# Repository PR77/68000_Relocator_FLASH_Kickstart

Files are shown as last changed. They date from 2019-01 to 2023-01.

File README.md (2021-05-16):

# 68000 Relocator with FLASH based Kickstart
Forked from https://github.com/AwesomeInferno/68000Relocator and modified to support FLASH Kickstart allowing programming in system.

# Warning
This design has not been compliance tested and will not be. It may cause damage to your A500. I take no responsibility for this. I accept no responsibility for any damage to any equipment that results from the use of this design and its components. IT IS ENTIRELY AT YOUR OWN RISK!

# Overview
To allow for Flash Kickstart images to be mapped in the same address space as existing ROM Kickstart without the need to remove the existing ROM. This design is targeting an accelerated A500(+) system which also require a CPU relocation.

### Appearance
Nice 3D model:
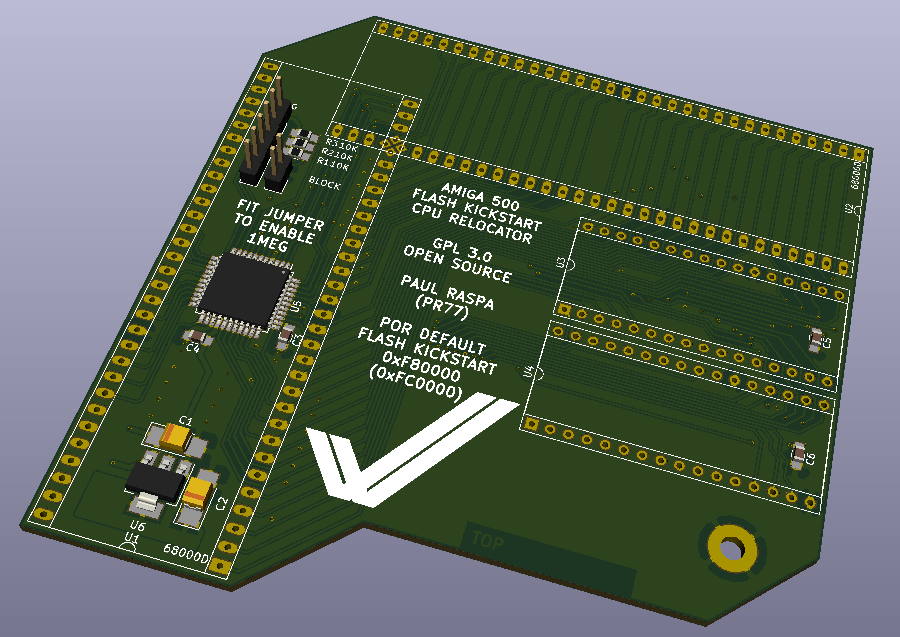
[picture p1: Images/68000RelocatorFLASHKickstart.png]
3D Model


... this is the final design.

### Prototype
Drawing in from the experience and usefulness of my prototyping jig created for my Rev-1 Accelerator (https://github.com/PR77/A500_ACCEL_RAM_IDE-Rev-1), I decided to do the same for this hardware expansion.

So the prototype looks like this:

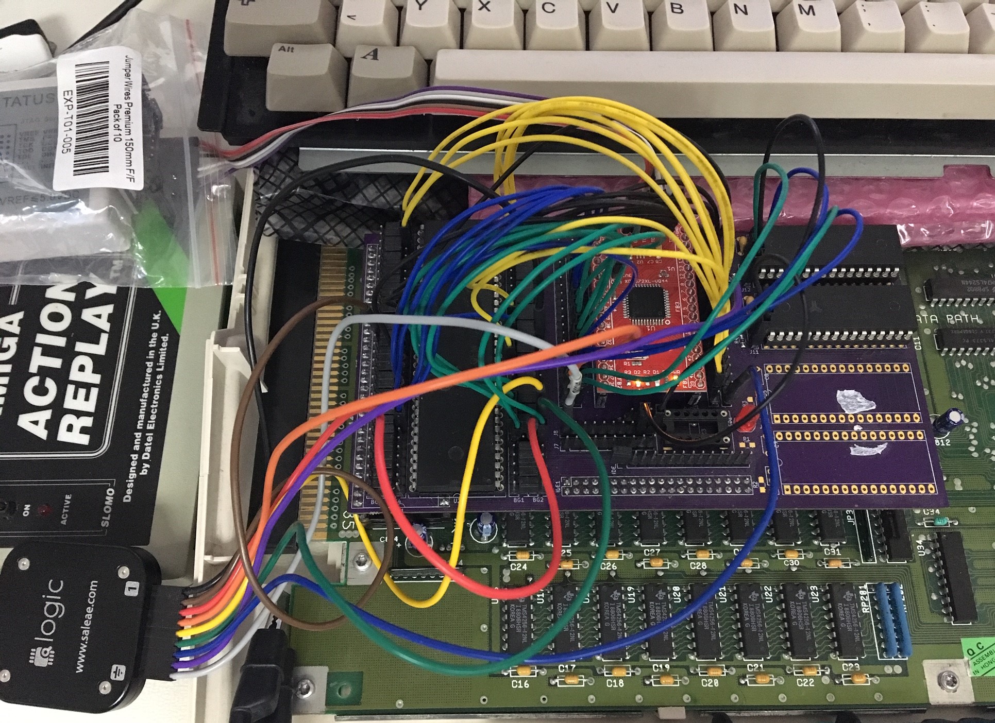
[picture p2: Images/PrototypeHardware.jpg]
Jumpered PCB


To keep the prototype simple, instead of using Flash devices (AMD AM29F040B are my target has I have these and experience with the devices) I used simple SRAMs (also from my Accelerator). There was also the learning curve with using VBCC (http://eab.abime.net/showthread.php?t=83113) to develop the software to control the hardware, but with that sorted out I managed to finally get the prototype to work.

### Final Hardware
Here is the final hardware loaded and installed with my Rev-2 Accelerator (https://github.com/PR77/A500_ACCEL_RAM_IDE-Rev-2). I was not able to easily source new AMD AM29F040B Flash devices so I changed over to SST39SF0x0A devices. They are JEDEC compliant so no issue with the pinout. Just watch out for the device identification in the SW.

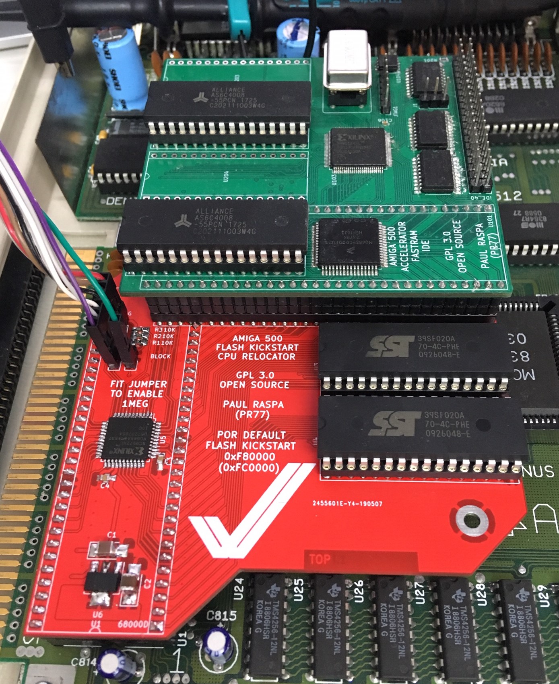
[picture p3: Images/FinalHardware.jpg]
Final PCB


### BOM
For those wanting to build their own hardware, here is the BOM;

| Reference(s) | Value | Footprint |
|---|---|---|
| C1 | 10uF | Capacitors_Tantalum_SMD:CP_Tantalum_Case-B_EIA-3528-21_Hand |
| C2 | 10uF | Capacitors_Tantalum_SMD:CP_Tantalum_Case-B_EIA-3528-21_Hand |
| C3 | 100nF | Capacitors_SMD:C_0805_HandSoldering |
| C4 | 100nF | Capacitors_SMD:C_0805_HandSoldering |
| C5 | 100nF | Capacitors_SMD:C_0805_HandSoldering |
| C6 | 100nF | Capacitors_SMD:C_0805_HandSoldering |
| J3 | BLOCK | Pin_Headers:Pin_Header_Straight_1x02_Pitch2.54mm |
| J4 | JTAG | Pin_Headers:Pin_Header_Straight_1x06_Pitch2.54mm |
| R1 | 10K | Resistors_SMD:R_0805_HandSoldering |
| R2 | 10K | Resistors_SMD:R_0805_HandSoldering |
| R3 | 10K | Resistors_SMD:R_0805_HandSoldering |
| U1 | 68000D | Pin_Headers:Pin_Header_Straight_2x32_Pitch2.54mm |
| U2 | 68000D | Housings_DIP:DIP-64_W22.86mm_Socket_LongPads |
| U3 | SST39SF040 | Housings_DIP:DIP-32_W15.24mm_Socket |
| U4 | SST39SF040 | Housings_DIP:DIP-32_W15.24mm_Socket |
| U5 | XC9572VQ44 | Housings_QFP:TQFP-44_10x10mm_Pitch0.8mm |
| U6 | LM1117-3.3 | TO_SOT_Packages_SMD:SOT-223-3_TabPin2 |

### In Operation
My test Amiga 500 has a ROM Kickstart version 1.2, so the boot screen looks like this:

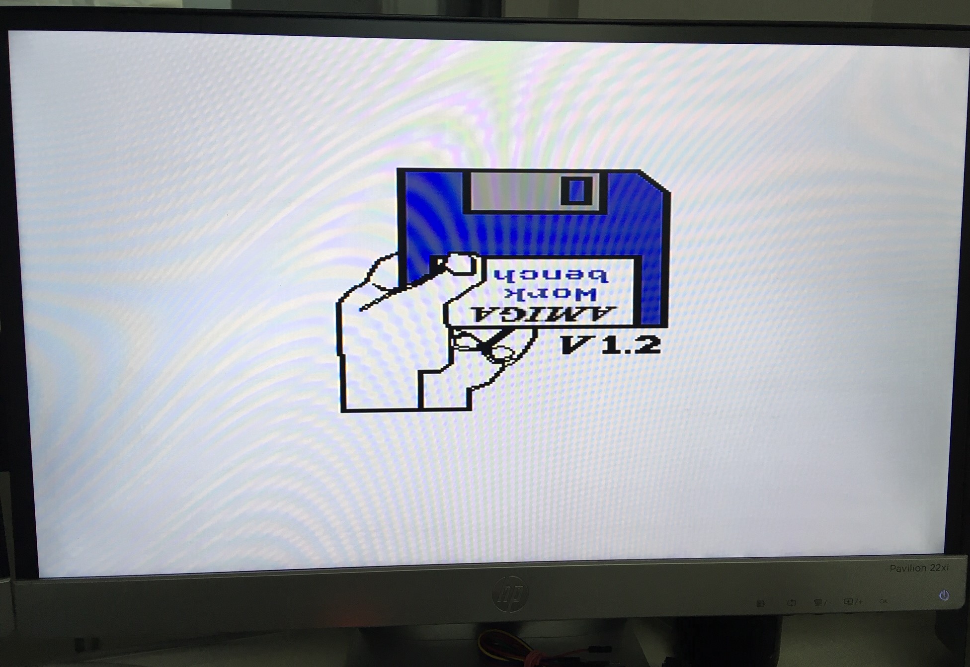
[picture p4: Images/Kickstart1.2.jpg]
ROM Kickstart 1.2


Then when loading into RAM Kickstart version 3.1 the software will make a simple dump of the RAM to the console to ensure it has been written correctly (data blurred to avoid any potential (C) issues). Essentially some basic debugging which looks like this:

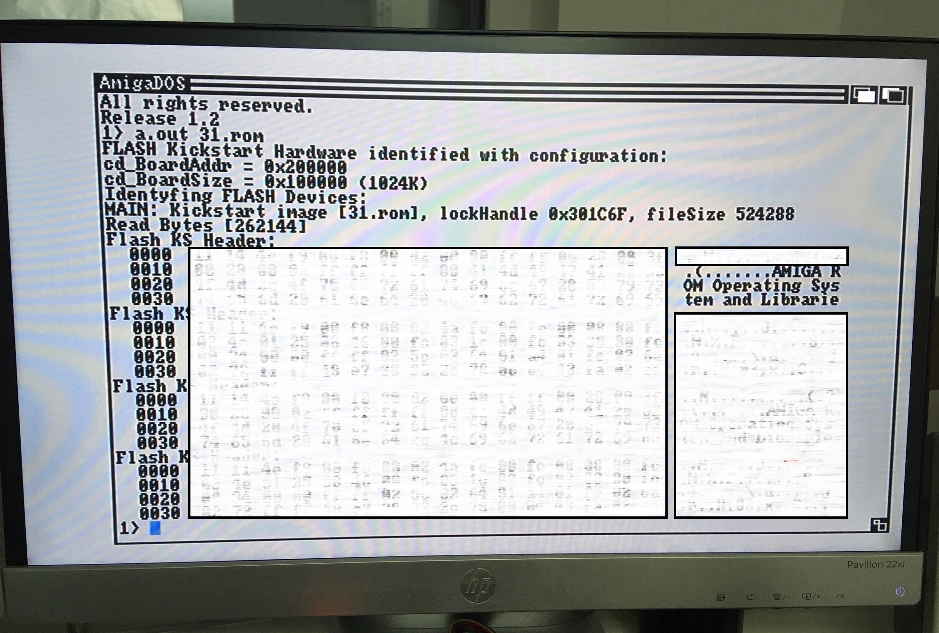
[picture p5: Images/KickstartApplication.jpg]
Application Output


... so now, using the magic sequence, I have Kickstart version 3.1 as shown here:

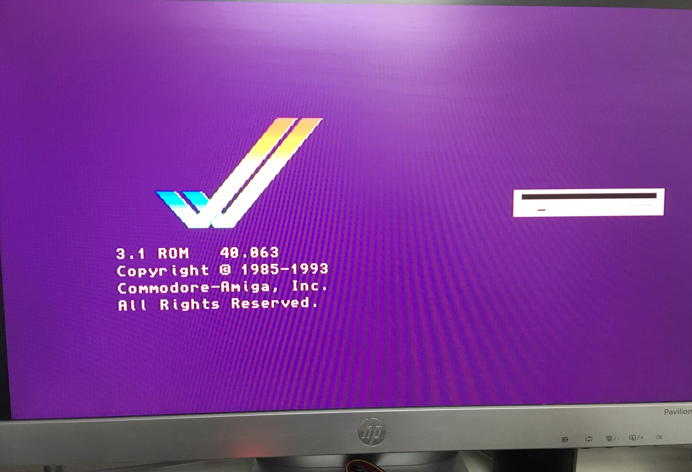
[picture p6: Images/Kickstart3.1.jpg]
ROM Kickstart 3.1


### How It Works
In principle the operation is fairly simple. A CPLD is used to switch between the ROM Kickstart on the Motherboard or the Flash Kickstart on the CPU Relocator. Switching is performed by an active /RESET (CTRL-A-A) without interruption for longer than 1 second. Shorter /RESET durations will simply just reset the Amiga. After a POR (Power On Reset) by default the Flash Kickstart on the CPU Relocator will be used.

#### ROM based Kickstart
When ROM Kickstart is being used, the hardware simply passed /AS to the Amiga Motherboard to allow GARY perform the address decode and chip select of the internal ROM. During this process, the Flash Kickstart is simply not used - except when programming. A Zorro II space of 512K is  requested and allocated by the Amiga which maps to the Flash devices.

When programming the Flash devices, access is via this Zorro II space. Programming of the Flash devices can only be performed when ROM Kickstart is being used.

#### FLASH based Kickstart
When Flash Kickstart is being used, the hardware simply blocks /AS to the Amiga Motherboard and the CPLD will perform the operation of Flash device control. As /AS is not asserted on the Amiga Motherboard, and therefore no GARY decode, the Relocator CPLD will then also assert the /DTACK after placing data on the bus - this is needed to complete the CPU cycle.

Flash Kickstarts will always be visible from base address 0xF80000. This means, if 256K images would be used, then it will need to be duplicated to populate the entire 512K region size. This is to ensure the correct SP and IP initisation (see Overlay Interception). 256K images generally start from address 0xFC0000 (as opposed to 0xF80000).

#### Overlay Interception
When Flash Kickstart mode is being used, the CPLD will also intercept the overlay of the Kickstart in the 0x000000 memory space until the first access to the custom chip register is performed. This ensures the correct SP and IP initialisation is performed directly after POR (Power On Reset) as the Flash Kickstart is used by default.

### Known Issues And Pending Items
The following items are pending:

1. Will update the software to not load the entire Kickstart content into RAM before programming; rather will load 64K chunks at a time.
2. Support for ROMs based at address 0xF00000.

### External Contributions
Thanks to the Open Source efforts, here is a list of improvements people have made:

1. Side Slot expander version and GUI - https://github.com/KaiEmilW/A500-Side-Expansion-Slot-CPU-Relocator

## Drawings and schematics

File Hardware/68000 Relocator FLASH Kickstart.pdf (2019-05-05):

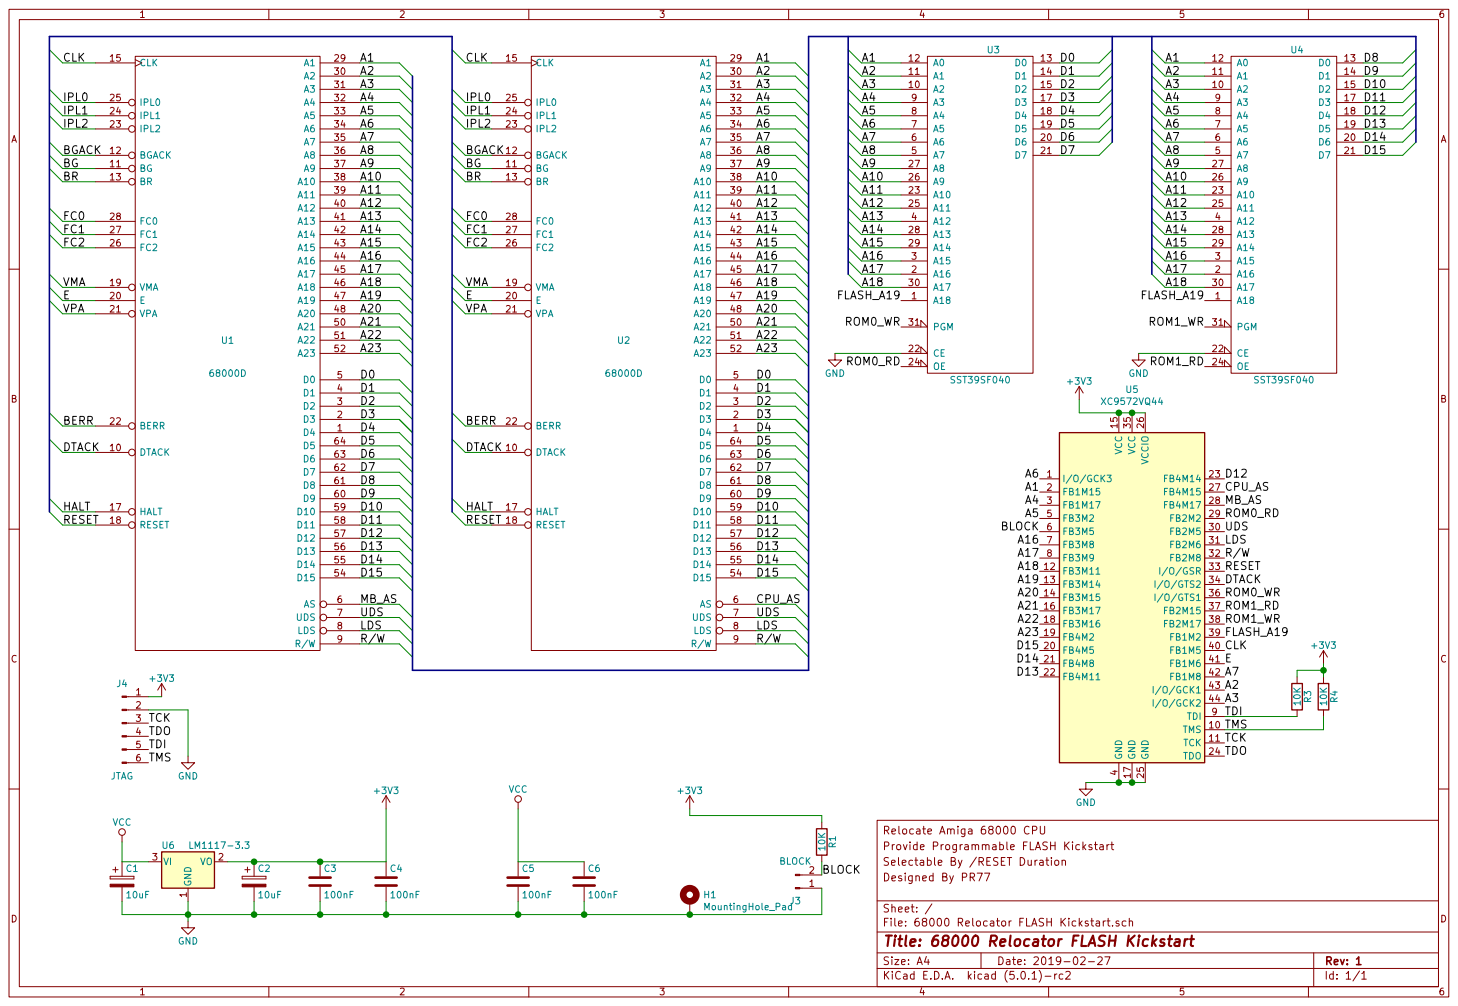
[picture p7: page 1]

Relocate Amiga 68000 CPU
Provide Programmable FLASH Kickstart
Selectable By /RESET Duration
Id: 1/1 Title: 68000 Relocator FLASH Kickstart File: 68000 Relocator FLASH Kickstart.sch Sheet: / Designed By PR77

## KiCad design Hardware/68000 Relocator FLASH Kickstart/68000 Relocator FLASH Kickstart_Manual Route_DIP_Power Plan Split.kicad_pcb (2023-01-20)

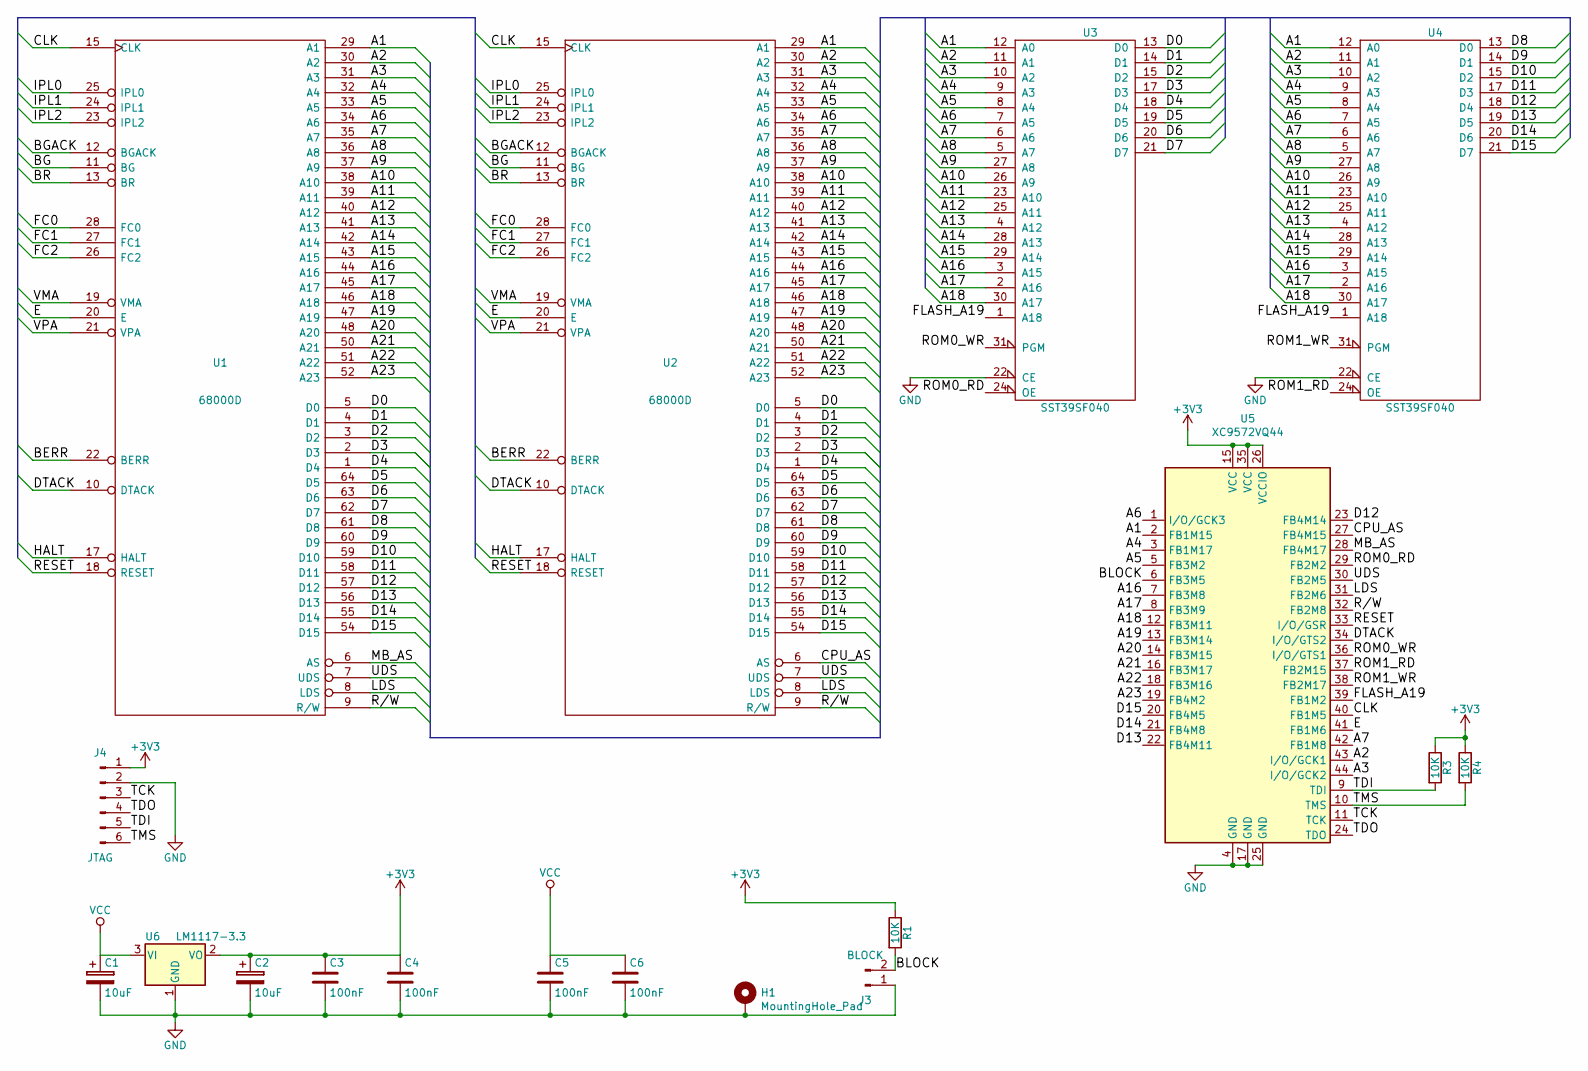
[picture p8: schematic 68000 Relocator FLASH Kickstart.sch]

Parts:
C1, C2: 10uF; CP_Tantalum_Case-B_EIA-3528-21_Hand
C3, C4, C5, C6: 100nF; C_0805_HandSoldering
H1: MountingHole_Pad; MountingHole_3.2mm_M3_Pad
J3: BLOCK; Pin_Header_Straight_1x02_Pitch2.54mm
J4: JTAG; Pin_Header_Straight_1x06_Pitch2.54mm
R1, R3, R4: 10K; R_0805_HandSoldering
U1, U2: 68000D; DIP-64_W22.86mm_Socket_LongPads
U3, U4: SST39SF040; DIP-32_W15.24mm_Socket
U5: XC9572VQ44; TQFP-44_10x10mm_Pitch0.8mm
U6: LM1117-3.3; SOT-223-3_TabPin2

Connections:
+3V3: C2.1, C3.1, C4.1, J4.1, R1.1, R3.1, R4.1, U5.15 (VCC), U5.26 (VCCIO), U5.35 (VCC), U6.2 (VO); also elsewhere on the board
/A1: U1.29 (A1), U2.29 (A1), U3.12 (A0), U4.12 (A0), U5.2 (FB1M15)
/A2: U1.30 (A2), U2.30 (A2), U3.11 (A1), U4.11 (A1), U5.43 (I/O/GCK1)
/A3: U1.31 (A3), U2.31 (A3), U3.10 (A2), U4.10 (A2), U5.44 (I/O/GCK2)
/A4: U1.32 (A4), U2.32 (A4), U3.9 (A3), U4.9 (A3), U5.3 (FB1M17)
/A5: U1.33 (A5), U2.33 (A5), U3.8 (A4), U4.8 (A4), U5.5 (FB3M2)
/A6: U1.34 (A6), U2.34 (A6), U3.7 (A5), U4.7 (A5), U5.1 (I/O/GCK3)
/A7: U1.35 (A7), U2.35 (A7), U3.6 (A6), U4.6 (A6), U5.42 (FB1M8)
/A8: U1.36 (A8), U2.36 (A8), U3.5 (A7), U4.5 (A7)
/A9: U1.37 (A9), U2.37 (A9), U3.27 (A8), U4.27 (A8)
/A10: U1.38 (A10), U2.38 (A10), U3.26 (A9), U4.26 (A9)
/A11: U1.39 (A11), U2.39 (A11), U3.23 (A10), U4.23 (A10)
/A12: U1.40 (A12), U2.40 (A12), U3.25 (A11), U4.25 (A11)
/A13: U1.41 (A13), U2.41 (A13), U3.4 (A12), U4.4 (A12)
/A14: U1.42 (A14), U2.42 (A14), U3.28 (A13), U4.28 (A13)
/A15: U1.43 (A15), U2.43 (A15), U3.29 (A14), U4.29 (A14)
/A16: U1.44 (A16), U2.44 (A16), U3.3 (A15), U4.3 (A15), U5.7 (FB3M8)
/A17: U1.45 (A17), U2.45 (A17), U3.2 (A16), U4.2 (A16), U5.8 (FB3M9)
/A18: U1.46 (A18), U2.46 (A18), U3.30 (A17), U4.30 (A17), U5.12 (FB3M11)
/A19: U1.47 (A19), U2.47 (A19), U5.13 (FB3M14)
/A20: U1.48 (A20), U2.48 (A20), U5.14 (FB3M15)
/A21: U1.50 (A21), U2.50 (A21), U5.16 (FB3M17)
/A22: U1.51 (A22), U2.51 (A22), U5.18 (FB3M16)
/A23: U1.52 (A23), U2.52 (A23), U5.19 (FB4M2)
/BERR: U1.22 (BERR), U2.22 (BERR)
/BG: U1.11 (BG), U2.11 (BG)
/BGACK: U1.12 (BGACK), U2.12 (BGACK)
/BLOCK: J3.2, R1.2, U5.6 (FB3M5)
/BR: U1.13 (BR), U2.13 (BR)
/CLK: U1.15 (CLK), U2.15 (CLK), U5.40 (FB1M5)
/CPU_AS: U2.6 (AS), U5.27 (FB4M15)
/D0: U1.5 (D0), U2.5 (D0), U3.13 (D0)
/D1: U1.4 (D1), U2.4 (D1), U3.14 (D1)
/D2: U1.3 (D2), U2.3 (D2), U3.15 (D2)
/D3: U1.2 (D3), U2.2 (D3), U3.17 (D3)
/D4: U1.1 (D4), U2.1 (D4), U3.18 (D4)
/D5: U1.64 (D5), U2.64 (D5), U3.19 (D5)
/D6: U1.63 (D6), U2.63 (D6), U3.20 (D6)
/D7: U1.62 (D7), U2.62 (D7), U3.21 (D7)
/D8: U1.61 (D8), U2.61 (D8), U4.13 (D0)
/D9: U1.60 (D9), U2.60 (D9), U4.14 (D1)
/D10: U1.59 (D10), U2.59 (D10), U4.15 (D2)
/D11: U1.58 (D11), U2.58 (D11), U4.17 (D3)
/D12: U1.57 (D12), U2.57 (D12), U4.18 (D4), U5.23 (FB4M14)
/D13: U1.56 (D13), U2.56 (D13), U4.19 (D5), U5.22 (FB4M11)
/D14: U1.55 (D14), U2.55 (D14), U4.20 (D6), U5.21 (FB4M8)
/D15: U1.54 (D15), U2.54 (D15), U4.21 (D7), U5.20 (FB4M5)
/DTACK: U1.10 (DTACK), U2.10 (DTACK), U5.34 (I/O/GTS2)
/E: U1.20 (E), U2.20 (E), U5.41 (FB1M6)
/FC0: U1.28 (FC0), U2.28 (FC0)
/FC1: U1.27 (FC1), U2.27 (FC1)
/FC2: U1.26 (FC2), U2.26 (FC2)
/FLASH_A19: U3.1 (A18), U4.1 (A18), U5.39 (FB1M2)
/HALT: U1.17 (HALT), U2.17 (HALT)
/IPL0: U1.25 (IPL0), U2.25 (IPL0)
/IPL1: U1.24 (IPL1), U2.24 (IPL1)
/IPL2: U1.23 (IPL2), U2.23 (IPL2)
/LDS: U1.8 (LDS), U2.8 (LDS), U5.31 (FB2M6)
/MB_AS: U1.6 (AS), U5.28 (FB4M17)
/R/W: U1.9 (R/W), U2.9 (R/W), U5.32 (FB2M8)
/RESET: U1.18 (RESET), U2.18 (RESET), U5.33 (I/O/GSR)
/ROM0_RD: U3.24 (OE), U5.29 (FB2M2)
/ROM0_WR: U3.31 (PGM), U5.36 (I/O/GTS1)
/ROM1_RD: U4.24 (OE), U5.37 (FB2M15)
/ROM1_WR: U4.31 (PGM), U5.38 (FB2M17)
/TCK: J4.3, U5.11 (TCK)
/TDI: J4.5, R3.2, U5.9 (TDI)
/TDO: J4.4, U5.24 (TDO)
/TMS: J4.6, R4.2, U5.10 (TMS); also elsewhere on the board
/UDS: U1.7 (UDS), U2.7 (UDS), U5.30 (FB2M5)
/VMA: U1.19 (VMA), U2.19 (VMA)
/VPA: U1.21 (VPA), U2.21 (VPA)
GND: C1.2, C2.2, C3.2, C4.2, C5.2, C6.2, H1.1, J3.1, J4.2, U1.16 (GND), U1.53 (GND), U2.16 (GND), U2.53 (GND), U3.16 (GND), U3.22 (CE), U4.16 (GND), U4.22 (CE), U5.4 (GND), U5.17 (GND), U5.25 (GND), U6.1 (GND)
VCC: C1.1, C5.1, C6.1, U1.14 (VCC), U1.49 (VCC), U2.14 (VCC), U2.49 (VCC), U3.32 (VCC), U4.32 (VCC), U6.3 (VI)

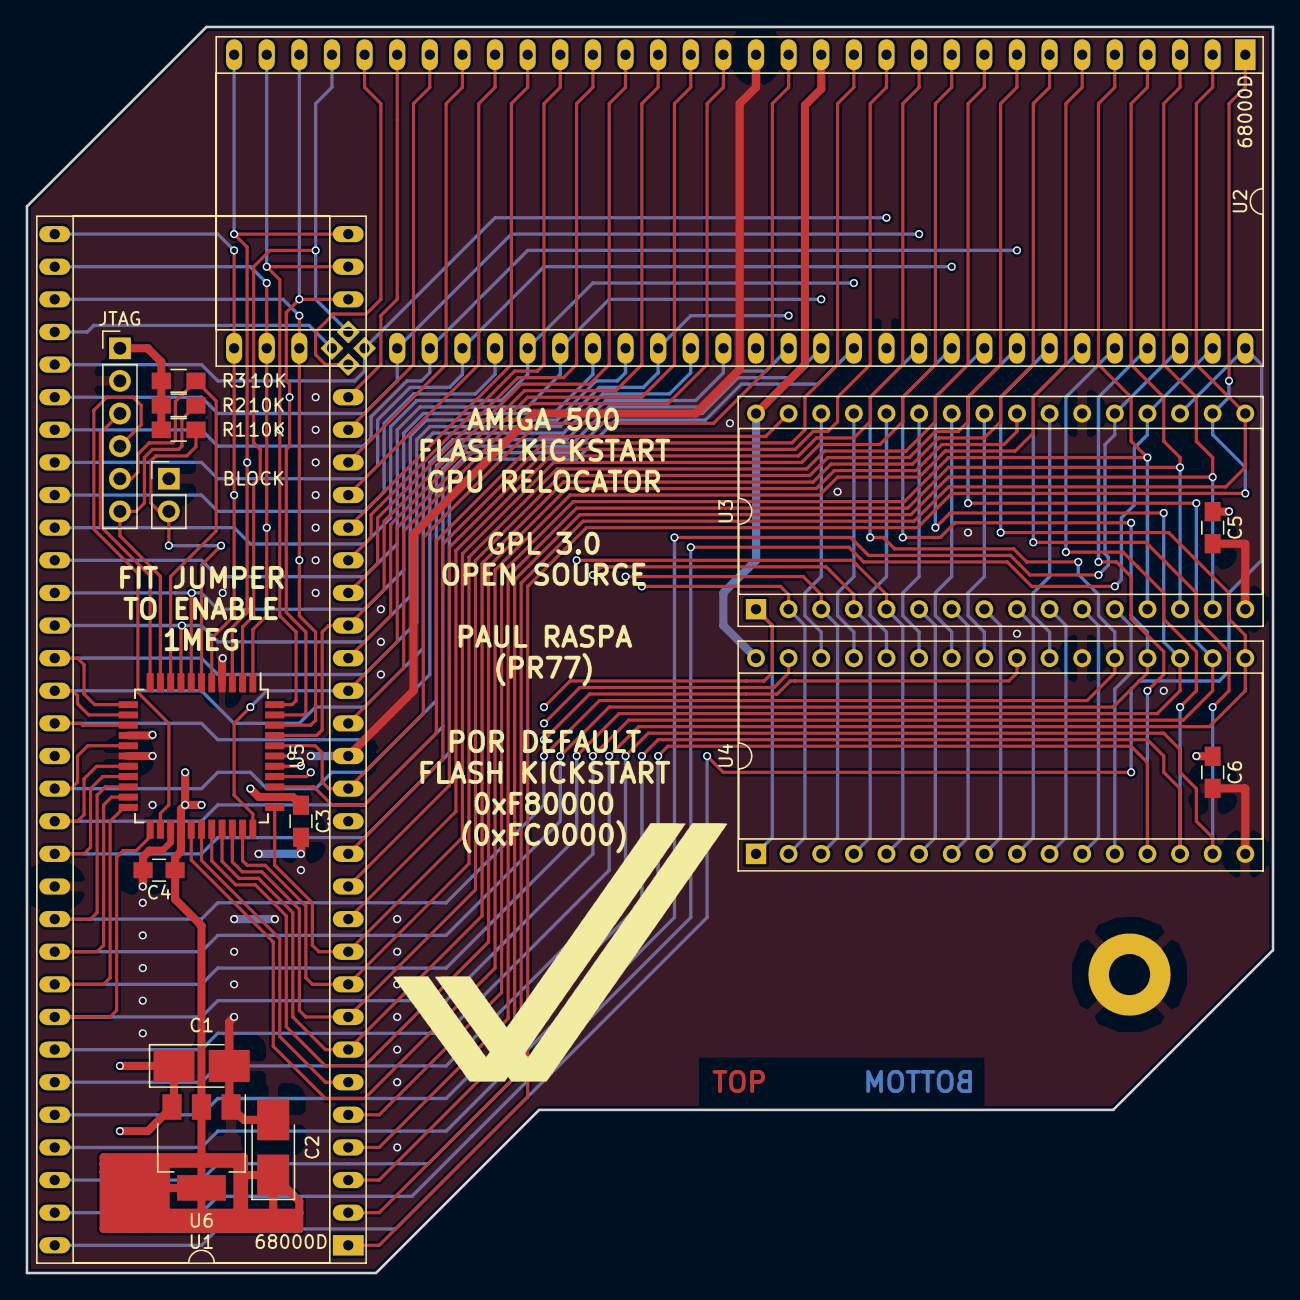
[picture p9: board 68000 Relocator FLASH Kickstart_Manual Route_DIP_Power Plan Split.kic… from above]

Board: 4 copper layers, 97.0 x 97.0 mm, 18 parts (0 on the bottom side), 74 nets.

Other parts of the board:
R2: 10K; R_0805_HandSoldering

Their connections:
+3V3: R2.1; also elsewhere on the board
/TMS: R2.2; also elsewhere on the board

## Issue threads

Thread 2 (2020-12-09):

Can't get it to work.

mheyer32, 2020-12-09:
I built the board, programmed the CPLD successfully, but I get no response from the system when turning on the machine.
Probing the address lines and data lines it looks like there's no activity at all. The HALT line is low. I can see that the clock signal reaches the CPLD.
Do you have any tips on how to debug this?
I am using a Rev8a board with a Kickstart 3.1.4 ROM

PR77, 2020-12-09:
Hi There,

Are you seeing activity on the /AS output of the CPLD and CPU? If you have no RAM installed, please try with DiagROM. Additionally, check for dry joints.

mheyer32, 2020-12-09:
I'll check the /AS activity tonight. I checked for unsoldered/bridged contacts multiple times, even replaced the CPLD with a spare one.
The flash chips are not programmed yet.
I tried switching to the original kickstart by holding Ctrl+Amiga+Amiga for several seconds, but to no avail.

PR77, 2020-12-10:
Could you also share some pictures? In addition to that are you using an accelerator board or just the CPU?

mheyer32, 2020-12-10:
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

Im planning to use it with. TF536, but for I’ll just test with the basic 68k

mheyer32, 2020-12-10:
/AS is high on both, CPU and MB. The CPU signal is at ca 4V, while the MB signal is at ca 3.3V

PR77, 2020-12-10:
To me, on the second photo it looks like a short on the top left side of the CPLD. Have you done a continuity test between all neighbouring pins?

/AS_MB should be 3.3 volts as it is a CPLD output signal. 4V from the CPU seems a bit low. Is VCC_CPU @ 5 volts?

mheyer32, 2020-12-11:
VCC_CPU is stable +5V

mheyer32, 2020-12-11:
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

There are no bridges. There was a bit of flux left that made it look like a bridge. Sorry for the poor picture, it was taken using a looking glass and a phone :-)

PR77, 2020-12-11:
Just to be sure, have you buzzed out with a continuity test all pins are connected? Do you have a logic analyser or scope? Would help to see the /AS, /LDS, /UDS and /DTACK signals. Are you sure after each cold boot, you are holding down CTRL-A-A?

mheyer32, 2020-12-12:
I buzzed out the lines leading into the CPLD and they all seem fine.
I got a scope and a logic tester, but no logic analyser.

/AS, /LDS, /UDS and /DTACK signals are all high... with the exception of the CLK signal there's no activity on any of the CPU pins :-(

PR77, 2020-12-12:
Strange. If the /HALT is asserted (low) it is a good indication that the CPU hasn’t been able to read valid data from the bus. Is /BERR also low?

Do you have diagROM?

PR77, 2020-12-27:
Any luck? Is it now working?

mheyer32, 2020-12-27:
Sorry, I haven't had the time to work on it recently. I'll let you know once I have more info.

mheyer32, 2021-02-17:
I eventually got it to work tonight. What was ultimately the culprit were tiny soldering bridges on 2-3 flash rom and CPU connector pins. While soldering I might have scratched the neighboring silkscreen by the tiniest bit, uncovering the GND plane and creating a bridge. I was only able to see these under the microscope.

Maybe a future iteration of the board could increase the distance of the empty space between the pins and  GND?

Thanks for creating the board!!! ...off to testing :-D

tkurbad, 2021-04-09:
Wow, thanks for pointing this out @mheyer32 . Judging from the soldermask color, I bought my PCB from the same seller as you and just removed about 8 or so of those unexpected bridges. My board is now working as well.

Closed 2021-02-17.

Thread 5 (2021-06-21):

Compatibility with A590?

mheyer32, 2021-06-21:
I'm trying to get a A590 SCSI controller to work on my A500 (with the flash relocator and a TF536 installed).
I can get the system to boot, but it easily runs into a "SCSI bus lockup" with the drive light on and no further activity.
Removing the relocator gets rid of the lockups.

Could this be an autoconfig issue? The A500 doesn't have true autoconfig on the 68k bus, so how does the relocator make its 1mb ram slot visible to the system?

PR77, 2021-06-25:
Hi There,

Interesting issue. I don't have an A590 so I can't be sure, but if the system boots it is unlikely an Autoconfig issue. Does the issue only happen when using the Flash Kickstart or both?

Autoconfig is done by data being made available to the CPU at address 0xE80000. The Relocation will block /AS from being asserted until it's autoconfig cycle is complete then /AS in this memory are allowed to other devices - like the TF536 and A590. Do you have FastRAM installed on the A590?

Could you send a screenshot of all of the Autoconfig devices present in the system?

mheyer32, 2021-06-28:
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
This is with the A590, TF536 and KickRelocator in the machine

mheyer32, 2021-06-28:
I also tried without the TF536. In this case the machine will hang with a SCSI lockup early in the boot.
What you see in the comment above is the machine booting from IDE while the A590 is connected.
The A590 has two MB of fastram installed.

PR77, 2021-07-04:
I have no A590 so I am only speculating here, if it boots then perhaps it is not DMA related. I don't expect DMA to be an issue as the relocater doesn't map usable RAM. Does the issue happen when using ROM or FLASH Kickstart?

mheyer32, 2021-07-12:
Using LinuxJedi's FW, I only tested the onboard ROM (not Flash).

Could it be an issue with the A590/A2091 ROM code?

PR77, 2021-07-12:
As I don’t have an A590 I can only speculate, but if it is not working also with the ROM KIckstart I suspect the issue might be with something else.

You mentioned the issue is also happening without your accelerator card, what if you remove the relocator and use a 68k direct in the CPU socket?

Do you have a logic analyser or other debugging equipment?

mheyer32, 2021-07-13:
If I remove the relocator and just place a 68k in the socket, it works.

I do have a logic probe and a 4-channel oscilloscope.

PR77, 2021-07-13:
When you experience the lockup, does the system freeze or only SCSI access? Have you tried with the original firmware?

Are you able to probe the /AS, /OVR, /DTACK and /BR? Trigger of falling edge of /DTACK.

mheyer32, 2021-07-15:
The hang seems system wide. Even interrupt-driven music players stop playing.
What is weird is that I can even boot from the SCSI device, but certain operations (in particular whatever SysInfo does when you click on a device in the  "Drives" menu) cause the lockup.
I tested the original FW, but the same issue applies. I'll try to tap the requested signals, give me some time :-)

PR77, 2021-08-28:
Hi There, how are you getting on with the debugging?

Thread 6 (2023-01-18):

Gerbers update?

JaimieVandenbergh, 2023-01-18:
Seems the gerbers here don't work with the current PCB sites - jlc and osh get the network and holes but fail to find the actual PCB or screenprint details. KiCAD6 gets the same. Would it be possible to update/refresh the gerbers zip?

PR77, 2023-01-20:
Seems the ZIP file never had the complete set of gerber files - thanks for highlighting this. It has now been corrected.

Closed 2023-01-20.

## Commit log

2019-01-09 Updates
    Working with prototype hardware.
2019-05-05 Updates
    Finalised PCB layout.
2019-05-06 Updates
    Fixed bottom solder mask.
2019-05-22 Updates
    Add BOM.
2019-05-22 Updates
    Removed Datasheet from BOM listing.
2023-01-20 Updated Gerbers
    [68000 Relocator FLASH Kickstart.sch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]

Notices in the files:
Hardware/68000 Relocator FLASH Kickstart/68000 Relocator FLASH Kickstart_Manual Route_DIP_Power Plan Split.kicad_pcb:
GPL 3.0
